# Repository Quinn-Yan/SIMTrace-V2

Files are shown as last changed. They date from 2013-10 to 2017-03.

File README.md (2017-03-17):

# Osmocom SIMtrace

(C) 2010-2017 by Harald Welte <laforge@gnumonks.org>

SIMTtraceis a program that can be used for tracing the communication
between a phone and the SIM card.  More generally, it can trace any
ISO 7816 based smart card interface.

SIMtrace is part of the [Osmocom](https://osmocom.org/) Open Source
Mobile Communications project.

This repository contains a host program 'simtrace' as well as a patch
for wireshark (which is part of mainline wireshark since February 2012)

The corresponding device firmware source code can be found at
<http://git.osmocom.org/openpcd/>

## Homepage

The official homepage of the project is
<https://osmocom.org/projects/simtrace/wiki/>

GIT Repository
--------------

You can clone from the official simtrace.git repository using

	git clone git://git.osmocom.org/simtrace.git

There is a cgit interface at <http://git.osmocom.org/simtrace/>

## Documentation

There is a PDF user manual available from
<https://osmocom.org/attachments/download/2139/usermanual.pdf>

Mailing List
------------

Discussions related to simtrace are happening on the
simtrace@lists.osmocom.org mailing list, please see
<https://lists.osmocom.org/mailman/listinfo/simtrace> for subscription
options and the list archive.

Please observe the [Osmocom Mailing List
Rules](https://osmocom.org/projects/cellular-infrastructure/wiki/Mailing_List_Rules)
when posting.

Contributing
------------

Our coding standards are described at
<https://osmocom.org/projects/cellular-infrastructure/wiki/Coding_standards>

We us a e-mail based patch submission/review process on the
above-mentioned mailing list for contributions.

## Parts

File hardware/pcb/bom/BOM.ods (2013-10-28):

Id | Designator | Package | Quantity | Designation | digikey ref | link
1 | R17,R16,R2,R18 | SM0603 | 4 | 10K | RMCF0603JT10K0CT-ND | click me
2 | R14,R13 | SM0603 | 2 | 150R | P150GCT-ND | click me
3 | R1,R4,R5,R6,R7,R8,R12,R15,R19,R22,R23,R24 | SM0603 | 12 | 100K | P100KGCT-ND | click me
4 | R11,R3 | SM0603 | 2 | 1K5 | RMCF0603JT1K50CT-ND | click me
5 | R10,R9 | SM0603 | 2 | 27R | P27GCT-ND | click me
6 | C23,C20,C19,C16,C15,C9,C7,C4,C3,C24 | SM0603 | 10 | 100nF | 478-1239-1-ND | click me
7 | C22,C21 | SM0603 | 2 | 1uF | 490-1543-1-ND | click me
8 | C18,C17 | SM0603 | 2 | 10pF | 490-1403-1-ND | click me
9 | C13,C11 | SM0603 | 2 | 15pF | 709-1142-1-ND | click me
10 | C12,C1 | SM0603 | 2 | 2.2uF | 478-6212-1-ND | click me
11 | C10 | SM0603 | 1 | 1nF | 478-1215-1-ND | click me
12 | C6 | SM0603 | 1 | 10nF | 490-1512-1-ND | click me
13 | C5 | SM0603 | 1 | 33pF | 490-1415-1-ND | click me
14 | FB2,FB1 | SM0805 | 2 | FILTER | P10191CT-ND | click me
15 | IC3 | TQFP_64 | 1 | AT91SAM7S | AT91SAM7S128C-AU-ND | click me
16 | P2 | PIN_ARRAY-6X1 | 1 | DEBUG | do not place
17 | Q2,Q1 | SOT23_BC847 | 2 | BC847 | BC847CINCT-ND | click me
18 | SW1 | PUSH_BUTTON | 1 | RESET | P12932SCT-ND | click me
19 | SW2 | PUSH_BUTTON | 1 | BOOTLOADER | P12932SCT-ND | click me
20 | J1 | USB-MINI-B_UX60 | 1 | USB | H2959CT-ND | click me
21 | P4 | SIM_AMPHENOL | 1 | SIM | 101-00271-82-1-ND | click me
22 | IC4 | SSOP20_BDQ | 1 | CB3Q3244 | 296-19125-1-ND | click me
23 | R21,R20 | SM0603 | 2 | 10k1% | 311-10.0KHRCT-ND | click me
24 | IC1 | SOT23_5 | 1 | FPF2109 | FPF2109CT-ND
25 | IC2 | SOT26 | 1 | AP7332 | AP7332-3333W6-7DICT-ND | click me
26 | D1,D2,D3,D6 | SOD123 | 4 | Schottky MBR0530 | MBR0530CT-ND
27 | BT1 | PIN_ARRAY_2X1 | 1 | 4.5-6V | do not place
28 | U1 | SOC008_WIDE | 1 | FLASH | S25FL016A provided by manufacturer
29 | D5 | LED-0805 | 1 | GREEN | green LED (2.1-2.2V, 20mA) provided by manufacturer
30 | D4 | LED-0805 | 1 | RED | red LED (2.1-2.2V, 20mA) provided by manufacturer
31 | P1 | PIN_ARRAY_10X2 | 1 | JTAG | do not place
32 | JP2 | PIN_ARRAY_2X1 | 1 | ERASE | use 90° pin (see additional section)
33 | JP1 | PIN_ARRAY_2X1 | 1 | TEST | use 90° pin (see additional section) | click me
34 | J2 | JACK_2.5 | 1 | JACK_2.5 | CP-2523SJCT-ND | click me
35 | X1 | Q_49U3HMS | 1 | 18.432MHz | XC1252CT-ND | click me
36 | P3 | FFC_REBELSIM | 1 | REBELSIM | 609-1889-1-ND | click me
37 | C14 | SM0805 | 1 | 4.7uF | 445-1369-1-ND | click me
additional
 | jumper |  | 4 |  | S9337-ND | click me
 | pin array 90° |  | 1 |  | S1112E-36-ND | click me

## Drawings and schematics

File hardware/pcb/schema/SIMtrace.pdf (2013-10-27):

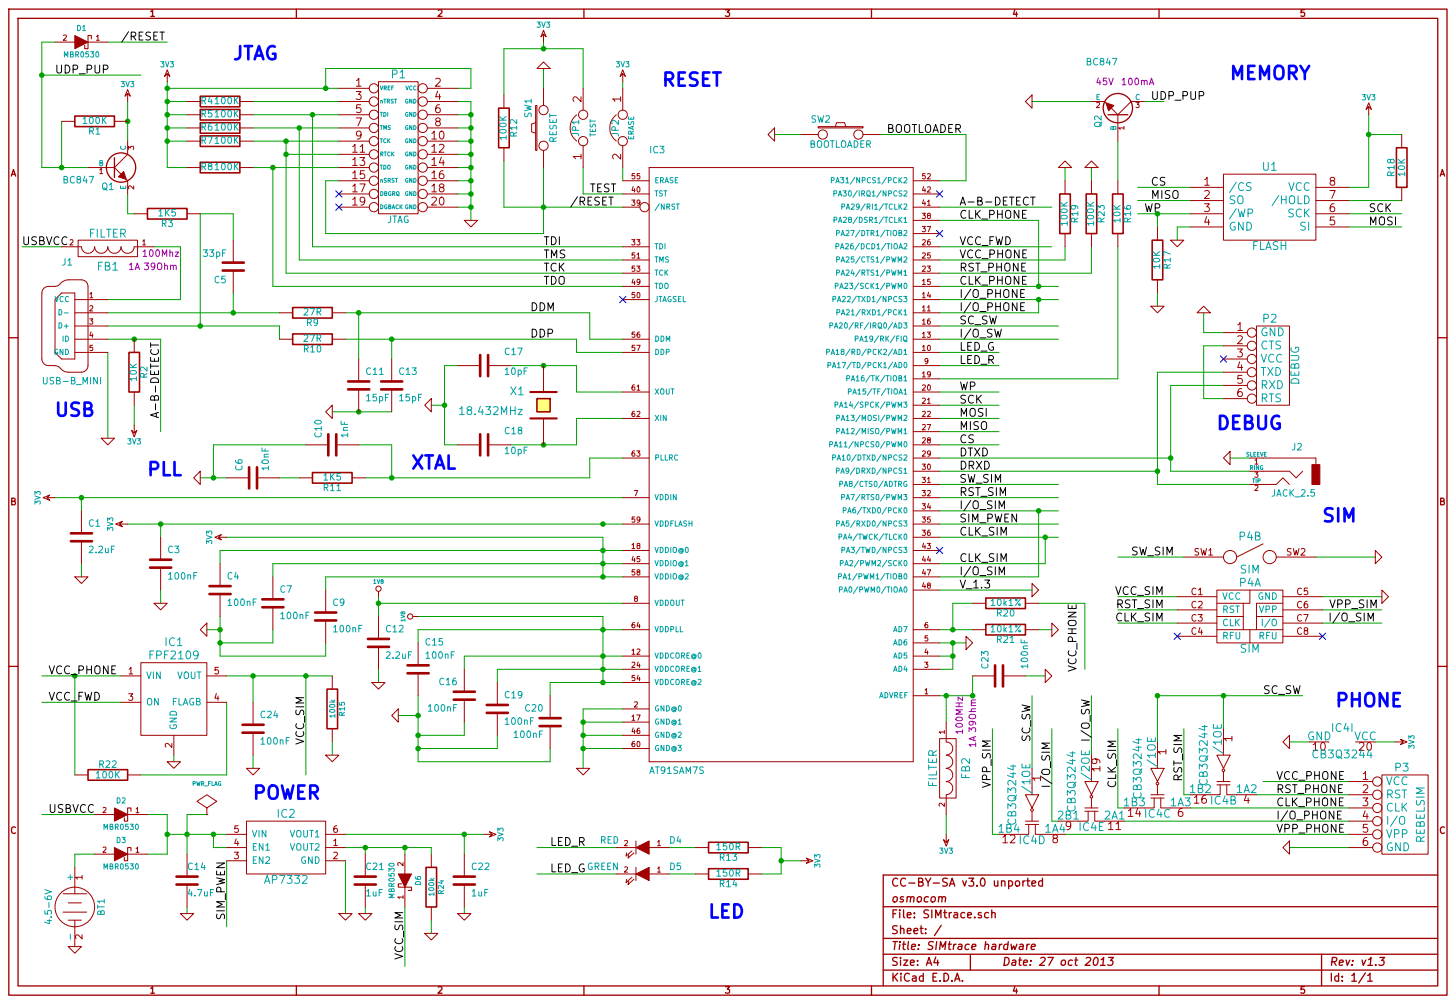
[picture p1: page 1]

/NRST 39 TDO 49 VDDFLASH 59 | | I/O_PHONE

TMS | | VCC_PHONE
TCK | | | RST_PHONE
TDO | | CLK_PHONE

I/O_PHONE

SIM_PWEN
CLK_SIM

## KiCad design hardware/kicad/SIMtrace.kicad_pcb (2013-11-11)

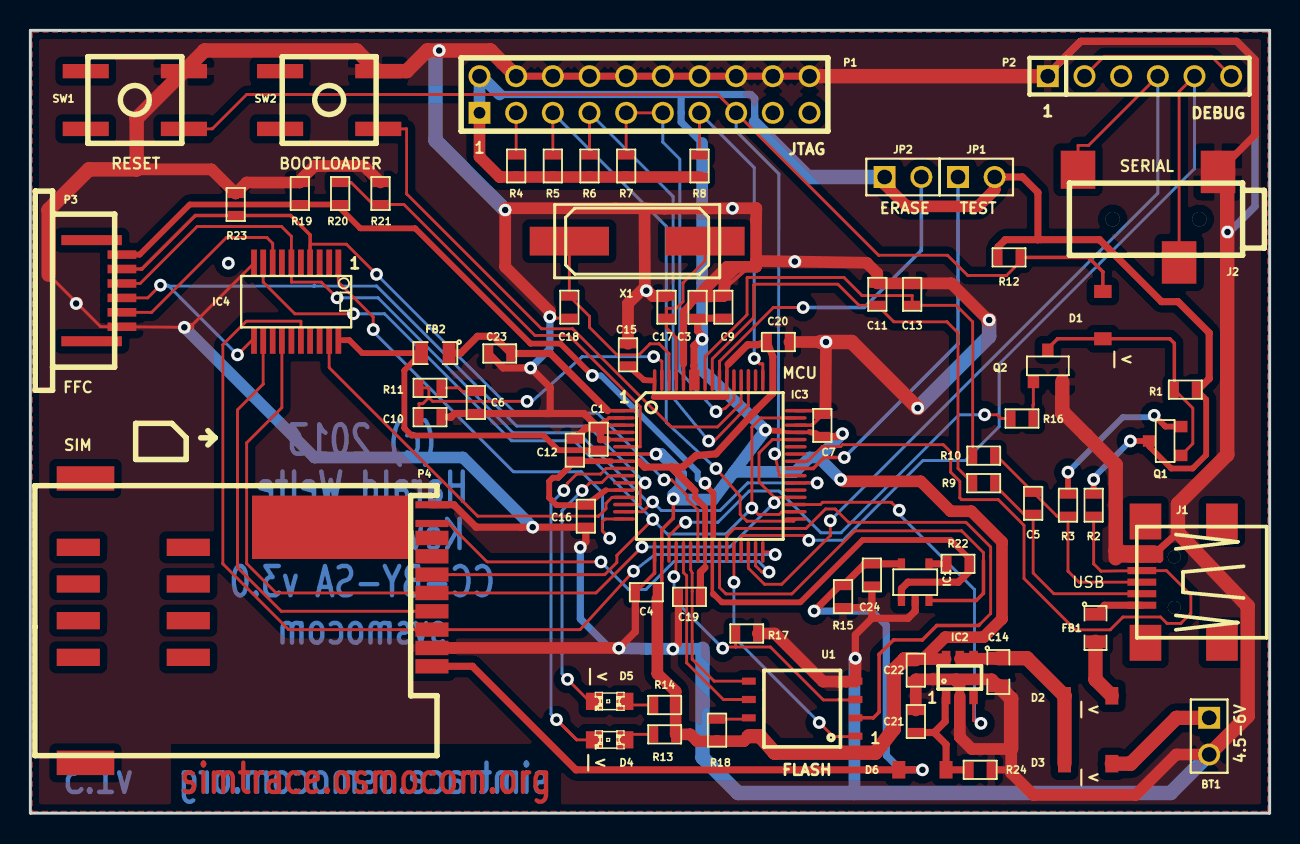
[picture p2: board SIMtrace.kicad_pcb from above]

Board: 2 copper layers, 85.9 x 54.2 mm, 73 parts (0 on the bottom side), 61 nets.

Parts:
BT1: 4.5-6V; PIN_ARRAY_2X1
C1, C12: 2.2uF; SM0603
C3, C4, C7, C9, C15, C16, C19, C20, C23, C24: 100nF; SM0603
C5: 33pF; SM0603
C6: 10nF; SM0603
C10: 1nF; SM0603
C11, C13: 15pF; SM0603
C14: 4.7uF; SM0805
C17, C18: 10pF; SM0603
C21, C22: 1uF; SM0603
D1, D2, D3, D6: MBR0530; SOD123
D4: RED; LED-0805
D5: GREEN; LED-0805
FB1, FB2: FILTER; SM0805
IC1: FPF2109; SOT23-5
IC2: AP7332; SOT26
IC3: MCU; TQFP_64
IC4: CB3Q3244; SSOP20_BDQ
J1: USB; USB-MINI-B_UX60
J2: SERIAL; JACK_2.5
JP1: TEST; PIN_ARRAY_2X1
JP2: ERASE; PIN_ARRAY_2X1
P1: JTAG; PIN_ARRAY_10X2
P2: DEBUG; PIN_ARRAY-6X1
P3: FFC; FFC_REBELSIM
P4: SIM; SIM_AMPHENOL
Q1, Q2: BC847; SOT23_BC847
R1, R4, R5, R6, R7, R8, R12, R19, R22, R23: 100K; SM0603
R2, R16, R17, R18: 10K; SM0603
R3, R11: 1K5; SM0603
R9, R10: 27R; SM0603
R13, R14: 150R; SM0603
R15, R24: 100k; SM0603
R20, R21: 10k1%; SM0603
SW1: RESET; PUSH_BUTTON
SW2: BOOTLOADER; PUSH_BUTTON
U1: FLASH; SOC008_WIDE
X1: 18.432MHz; Q_49U3HMS

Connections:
3V3: C1.1, C3.1, C4.1, C7.1, C9.1, C22.1, FB2.2, IC2.6, IC3.7, IC3.18, IC3.45, IC3.58, IC3.59, IC4.20, JP1.2, JP2.1, P1.1, P1.2, Q1.3, R1.1, R2.2, R4.2, R5.2, R6.2, R7.2, R8.2, R12.1, R13.1, R14.1, R18.2, U1.8
+1.8V: C12.1, C15.1, C16.1, C19.1, C20.1, IC3.8, IC3.12, IC3.24, IC3.54, IC3.64
//RESET: D1.1, IC3.39, P1.15, R12.2, SW1.1
/A-B-DETECT: IC3.41, J1.4, R2.1
/BOOTLOADER: IC3.52, SW2.1
/CLK_PHONE: IC3.15, IC3.38, IC4.6, P3.3
/CLK_SIM: IC3.36, IC3.44, IC4.14, P4.C3
/CS: IC3.28, U1.1
/DDM: C11.1, IC3.56, R9.1
/DDP: C13.1, IC3.57, R10.1
/DRXD: IC3.30, J2.2, P2.4
/DTXD: IC3.29, J2.3, P2.5
/I/O_PHONE: IC3.11, IC3.14, IC4.11, P3.4
/I/O_SIM: IC3.34, IC3.47, IC4.9, P4.C7
/I/O_SW: IC3.13, IC4.19
/LED_G: D5.2, IC3.10
/LED_R: D4.2, IC3.9
/MISO: IC3.27, U1.2
/MOSI: IC3.22, U1.5
/RST_PHONE: IC3.23, IC4.4, P3.2, R23.2
/RST_SIM: IC3.32, IC4.16, P4.C2
/SCK: IC3.21, U1.6
/SC_SW: IC3.16, IC4.1
/SIM_PWEN: IC2.3, IC3.35
/SW_SIM: IC3.31, P4.SW1
/TCK: IC3.53, P1.9, P1.11, R7.1
/TDI: IC3.33, P1.5, R5.1
/TDO: IC3.49, P1.13, R8.1
/TEST: IC3.40, JP1.1
/TMS: IC3.51, P1.7, R6.1
/UDP_PUP: D1.2, Q1.1, Q2.3, R1.2
/USBVCC: D2.2, FB1.2
/VCC_FWD: IC1.3, IC3.26
/VCC_PHONE: IC1.1, IC3.25, P3.1, R19.2, R20.1, R22.1
/VCC_SIM: C24.1, D6.1, IC1.5, P4.C1, R15.1
/VPP_PHONE: IC4.8, P3.5
/VPP_SIM: IC4.12, P4.C6
/WP: IC3.20, R17.1, U1.3
GND: BT1.2, C1.2, C3.2, C4.2, C6.1, C7.2, C9.2, C10.1, C11.2, C12.2, C13.2, C14.2, C15.2, C16.2, C17.2, C18.2, C19.2, C20.2, C21.2, C22.2, C23.2, C24.2, IC1.2, IC2.2, IC3.2, IC3.3, IC3.4, IC3.5, IC3.17, IC3.46, IC3.48, IC3.60, IC4.10, J1.5, J2.1, P1.4, P1.6, P1.8, P1.10, P1.12, P1.14, P1.16, P1.18, P1.20, P2.1, P3.6, P4.C5, P4.SW2, Q2.2, R15.2, R17.2, R19.1, R21.1, R23.1, R24.2, SW1.2, SW2.2, U1.4
unnamed: C6.2, R11.2
unnamed: R18.1, U1.7
unnamed: Q2.1, R16.1
unnamed: Q1.2, R3.2
unnamed: C21.1, D6.2, IC2.1, R24.1
unnamed: C5.2, J1.3, R3.1, R10.2
unnamed: IC3.19, R16.2
unnamed: P2.2, P2.6
unnamed: BT1.1, D3.2
unnamed: C17.1, IC3.61, X1.1
unnamed: C18.1, IC3.62, X1.2
unnamed: IC1.4, R22.2
unnamed: P1.3, R4.1
unnamed: C10.2, IC3.63, R11.1
unnamed: IC3.55, JP2.2
unnamed: D5.1, R14.2
unnamed: D4.1, R13.2
unnamed: C14.1, D2.1, D3.1, IC2.4, IC2.5
unnamed: C5.1, J1.2, R9.2
unnamed: FB1.1, J1.1
unnamed: C23.1, FB2.1, IC3.1
unnamed: IC3.6, R20.2, R21.2

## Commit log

2011-07-02 footprints for flash S25FL016A and schottky STPS340U created
2011-07-02 new footprints select for production in netlist (LED is 0805, schottky is SMB_STPS340U, flash is SO008_wide
    [SIMtrace.sch]
2011-07-02 board adapted to new footprints
    [SIMtrace.brd]
2011-07-02 PS/gerber rendered for production
    [SIMtrace-Back.gbl, SIMtrace-Comments.gbr, SIMtrace-Drawings.gbr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]
2011-07-02 BOM updated for production
    [BOM.ods, SIMtrace.csv]
2011-07-02 D2 and D3 now also use STPS340U instead of 1N5819
    [BOM.ods, SIMtrace.brd, SIMtrace.csv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]
2011-07-02 v1.0p corrected and rendered. BOM updated
    [BOM.ods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]
2011-11-01 ftdi 3.3v cut in schema
    [SIMtrace.sch]
2011-11-03 footprint refreched, cap near LDO
    [SIMtrace.brd, SIMtrace.sch]
2011-11-03 +1.8V line enlarged on C12, C15, C16. not possible on C19
    [SIMtrace.brd]
2011-11-05 VPP connected through bus switch
    [SIMtrace.brd, SIMtrace.sch]
2011-11-05 hw: solder mask between at91sam7s added
    [SIMtrace-Back.gbl, SIMtrace-Front.gtl, SIMtrace-Mask_Back.gbs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]
2011-11-05 hw: sysmocom added to copper, gerber rendered
    [SIMtrace-Back.gbl, SIMtrace-Front.gtl, SIMtrace-Mask_Back.gbs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]
2011-12-05 hw: fabrication output generated
    [SIMtrace.drl]
2012-05-15 SIMtrace: Improve PCB routing of GND, 3V3 and VCC traces
    We have to make sure the impedance of the supply lanes is not too high.
    Particularly bad was passing GND in 0.2mm under several resistors before
    even reaching the LDO from the USB socket.
    This attempts to address the major issues. Also, the input capacitor is
    moved closer to the LDO once again
    [SIMtrace.brd]
2012-05-15 DRC rules violations corrected
    [SIMtrace.brd]
2012-05-16 C14 change to 4.7uF 0805, silkscreen improved, more space for JTAG
    [SIMtrace.brd, SIMtrace.sch]
2012-05-16 v1.2p fabrication exported
    [BOM.ods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]
2012-05-17 Add R23 (pull-up for !SIM_RST signal)
    While the SAM7 has an internal pull-up, this is of no use if the bus
    switch input is left open and collects noise resulting in bogus nRST
    interrupts.
    [SIMtrace.sch]
2012-05-18 RST_PHONE pulldown added on PCB
    [BOM.ods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]
2012-05-19 Mark IC5 as "do not place" (VCC_Forward) as it doesn't work anyway
    If the LDO is switched off, then even if we try to forward power from
    the phone to the SIM, the current will sink inside the LDO (no reverse
    current protection).
    [BOM.ods]
2013-10-27 v1.3 modifications: replaced IC switch with FPF2109, added schottky and pull-down resistors
    [SIMtrace.sch]
2013-10-27 set footprints to symbols
2013-10-27 new KiCAD layout format, silkscreen refdes 0.5mm, text 0.75mm, new components loaded
    [SIMtrace.kicad_pcb]
2013-10-27 MBR0530 pin numbers corrected
    [SIMtrace.sch]
2013-10-27 new components placed and routed
    [SIMtrace.kicad_pcb]
2013-10-27 exported fabrication files
    [BOM.ods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]
2013-10-27 MCU pin 48 used to identify v1.3 by putting it to ground (with internal pull-up)
    [SIMtrace.brd, SIMtrace.kicad_pcb, SIMtrace.sch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]
2013-10-27 re-add BOM spreadsheet with updated v1.3 components
    [BOM.ods]
2013-10-28 BOM corrected (sorted by value) and reformated
    [SIMtrace.csv, SIMtrace.sch]
2013-11-11 simtrace 1.3: move point of origin to lower left corner of PCB
    [SIMtrace.kicad_pcb]
2013-11-16 add datasheet of SPI flash component mounted on recent boards
    At some point during v1.2p production, we switched from the S25FL016
    to the S25FL032P SPI flash model. v1.3 all have that flash (so far).
2014-04-26 add PCB design of mini-UICC (original and reverse) adapters
    [mini-UICC-reverse.stiffeners.gbr, mini-UICC-reverse.top.gbr, mini-UICC-reverse.topmask.gbr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]
2014-04-30 mini-UICC-reverse: re-generate gerber and add outline GBR
    [mini-UICC-reverse.outline.gbr, mini-UICC-reverse.top.gbr, mini-UICC-reverse.topmask.gbr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]
2015-08-19 Add 4FF (nanoSIM) adapter
    [4FF-FFC.bottom.gbr, 4FF-FFC.bottompaste.gbr, 4FF-FFC.fab.gbr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]
2016-04-01 remove second copy of mini-UICC FPC adapter
    [mini-UICC.outline.gbr, mini-UICC.stiffener.gbr, mini-UICC.top.gbr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]
2016-04-01 add 'sysmocom' name to mini-UICC and nano-UICC adapters
    As sysmocom is the only company manufacturing them for now, we add this
    branding to the design files.
    [4FF-FFC.bottom.gbr, 4FF-FFC.bottommask.gbr, 4FF-FFC.bottompaste.gbr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]
2017-03-17 update README with current information + convert to Markdown

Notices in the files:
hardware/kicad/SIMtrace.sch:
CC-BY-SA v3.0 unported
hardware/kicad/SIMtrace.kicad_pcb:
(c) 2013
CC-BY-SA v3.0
